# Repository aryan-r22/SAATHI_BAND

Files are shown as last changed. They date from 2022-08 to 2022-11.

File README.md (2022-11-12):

# SAATHI - Self Assessment & Alleviation by Technology & Healthcare Interface
## **Smart India Hackathon 2022 & Inter IIT Tech Meet 10.0**

### Description
SAATHI is an end-to-end IoT-based solution to help patients with anxiety spectrum disorders, track their mental health status, manage their cognitive behavior, and help them mitigate their issues by using a Smart wearable wristband and a mobile-based application which can be downloaded from [here](https://drive.google.com/file/d/1PYBU-KG3LGyAz-N6EyMyOQ441DeFL92f/view?usp=sharing).

### Directory Structure
- **End to end simulation files**: Consists of simulation files, circuit diagrams, codes and the necessary libraries for the MCU. Also included is a demonstration video for the entire implementation.
- **Fall detection**: Consists of scripts for implementing the algorithm for Fall detection.
- **Prototype 3DModel** - Consists of prototype files made on Fusion360.
- **Sleep detection** - Files for implementing the algorithm for Sleep detection.
- **Deployable codebase** - Single wrapper file for inference.
- **Stress_detection.ipynb** - Jupyter notebook to implement the stress detection algorithm.
- **SAATHI user flow.pdf**- A user flow diagram for the entire technical implementation of SAATHI.
- **Circuit Schematic Image.png** - The circuit schematic image for the entire approach.
- **Business Model Canvas.docx** - Document having the business model pictographics.
- **Anxiety Attack.pdf** - Flow diagram for anxiety attack detection algorithm.
- **Flow_OCD.pdf** - Flow diagram for OCD detection.
- **Important Links.xlsx** - Contains links for the references used for the entire project.
- **Finance Model.xlsx** - Contains data for the finance model of the entire product.
- **SAATHI.apk** - Mobile application for SAATHI ecosystem.
- **Final_Presentation** - Final pitch presentation.
- **Mid_Evaluation_Report** - Technical Report for the product.
- **SAATHI UI.mp4** - Mockup of the proposed UI for the mobile app.
- **Stress_Detection.ipynb** - Code file for stress detection.  

### Contributors
- Aditya Bharadwaj
- Aditya Naik
- Apurva Kamble
- Aryan Rastogi
- Ashish Gautam
- Ashwin Jino V
- Dhruv Parasrampuria
- Harshwardhan Chaube
- Kailaash Pandiyan
- Neelanshu Garg
- Samhith Damani
- V Logashree
- Vineet Tripathi

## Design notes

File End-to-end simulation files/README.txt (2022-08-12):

This folder has the following contents:

1) Libraries of the sensor modules used for proteus simulation - Proteus Libraries
2) Proteus project files in a folder.
3) A video explaining the end-to-end simulation - SAATHI end-to-end simulation.mp4
4) Arduino file used for simulation - Saathi.ino

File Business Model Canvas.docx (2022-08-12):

Business Model Canvas

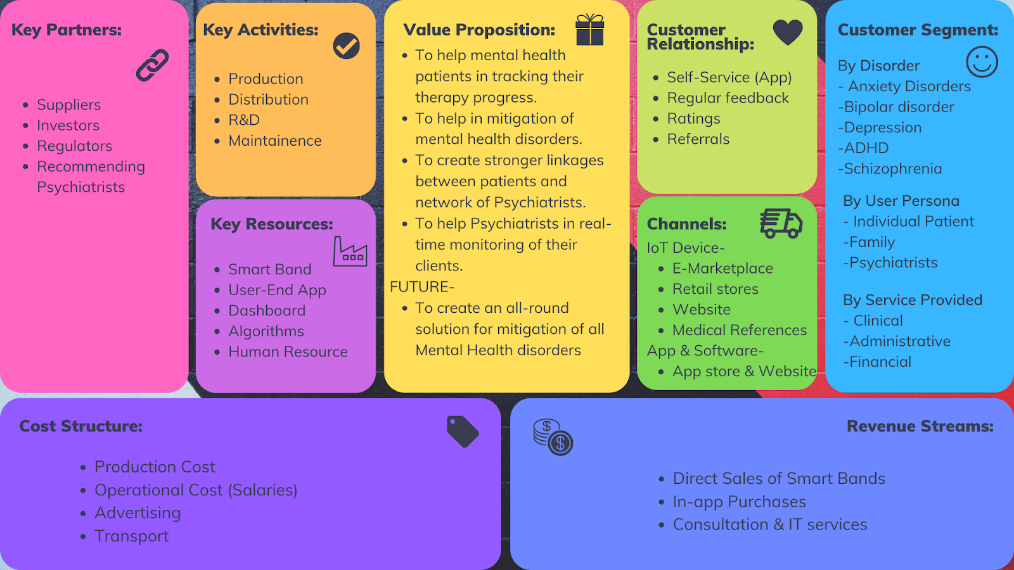
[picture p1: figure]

Unique Value proposition

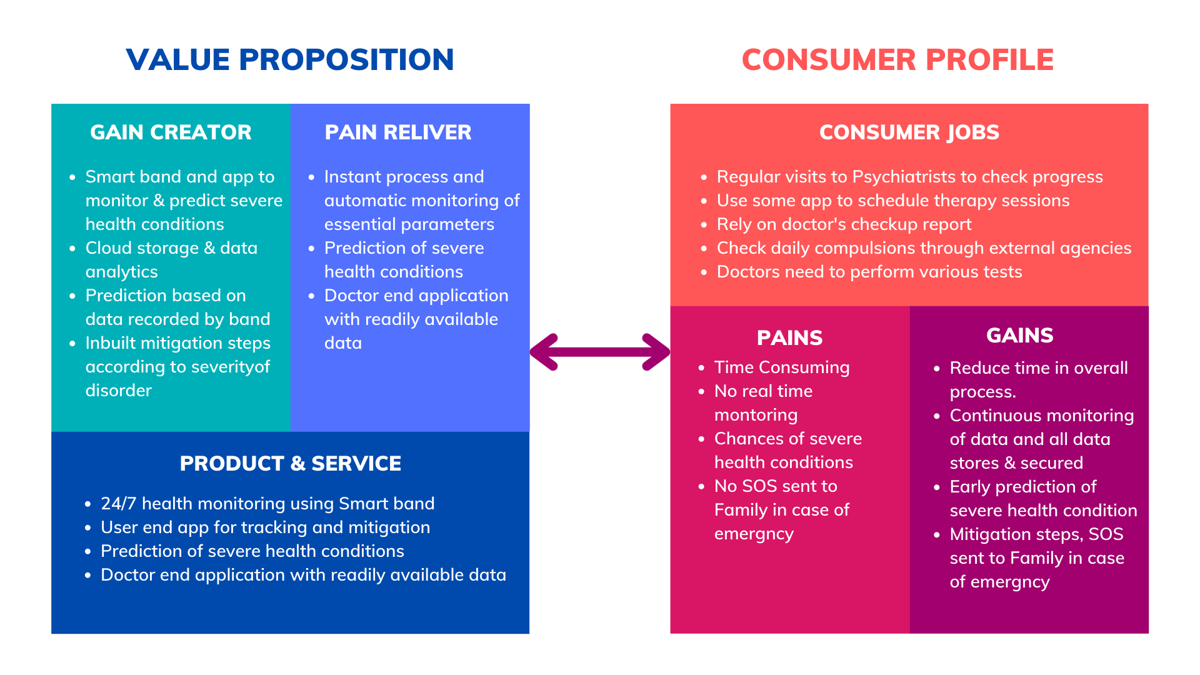
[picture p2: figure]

Customer Segmentation

As mental health is a very huge domain, we focus to help people with anxiety spectrum disorders. The product also lies in an affordable range and requires minimum internet connectivity, Hence it is meant for all sections of society

Persona 1 (Individual Patients)- Unable to track progress, Cannot store daily data. Do not have a personalized treatment plan.

Persona 2 (Family)- Keep track of the status of loved ones. Encourage family & community support.

Persona 3 (Psychiatrist)- Need for the patient management system. Need for data during consultation.

Customer Channels

Distribution channels include Physical & Virtual channels as follows-

Physical Channel This channel is only applicable for IoT devices (Smart Band). Physical sale in Pharmacy shops. Referrals by other patients and doctors | Virtual channel For IoT devices- InApp Purchases, Website, E-Marketplace For App- Appstore & Website For Software- Website

Customer Relationship

The healthy relationship between users and company can be marked by-

- Regular feedback of prediction model.
- Regular feedback of App support.
- Referrals of App/Bands.
- Ratings on several websites.

Revenue Stream

All these customer-side business interventions will generate revenue streams for the company.

Details- https://docs.google.com/spreadsheets/d/1tGmC5ilvg3ST7chS3FKTNZqF0qSboc8x575JbDMljg8/edit?usp=sharing

Key Activities

This includes a crucial part of the Business Value chain. The main operation of the Business is concerned with the Production, Distribution of smart devices, advertising, and maintenance.

Frequent updates in App and Software, Database management, Other business legalities.

Giving impetus to Research and Development for the launch of new products/services. Also taking its due approval from BIS or any other certifying agency.

Key Resources

Our key resources include all the essential files/codes/product from the origination to the termination of the value chain. Human Capital.

Key Partners

These include regulators those who approve our products, Psychiatrists who recommend our products, Investors as well as suppliers

Cost Structure

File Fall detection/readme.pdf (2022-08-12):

# Fall detection using Machine Learning -SAATHI

## Team 17 - Silicon Labs Entreprenuership Challenge

Inter IIT Tech Meet 10.0

Description

This machine learning algorithm detects fall detection using accelerometer and gyroscope sensors, both of which are present in our IoT based healthcare solution.

We have used the XGBoost algorithm for fall detection, which is renowned for its performance and efficiency gains. The dataset used is SisFall: A Fall and Movement Dataset [1], (http://sistemic.udea.edu.co/en/investigacion/proyectos/english-falls/) which is available in open domain. We envision our model to be dynamically trained on the data collected by our device, which ensures that our algorithm adapts to the the different variations in external conditions of use.

Running the code

Download the dataset zip files from the following links:

https://drive.google.com/uc?id=1gvOuxPc8dNgTnxuvPcVuCKifOf98-TV0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

Run Data_preparation.py to prepare the data in the required format for training.
Run Train.py to train the XGBoost model on the generated data and save the trained model for future inference.
Run Eval.py to get the metrics on the test split of the SisFall dataset.

Metrics on Test Split

Classification Accuracy = 98.04%
F1 Score (Weighted) = 97.95%
Precision (Weighted) = 97.92%
Recall (Weighted) = 98.04%

Our model performs exceptionally well, and exceeds the performance of the existing approaches on this dataset [2]. (https://www.ncbi.nlm.nih.gov/pmc/articles/PMC5298771/)

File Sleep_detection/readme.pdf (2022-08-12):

# Sleep detection using Machine Learning -SAATHI

## Team 17 - Silicon Labs Entreprenuership Challenge

Inter IIT Tech Meet 10.0

Description

This machine learning algorithm detects the sleep cycles on the basis of the accelerometer data recorded by our IoT-based healthcare solution.

We have used the XGBoost algorithm for fall detection, which is renowned for its performance and efficiency gains. Principal Component Analysis (PCA) was additionally used to transform the data to a lower dimension. The dataset used is ICHI 14 [1], (https://www.researchgate.net/publication/305212784_ICHI14-Borazio) which is available in open domain. We envision our model to be dynamically trained on the data collected by our device, which ensures that our algorithm adapts to the the different variations in external conditions of use.

Our machine learning algorithm provides predictions regarding the sleep stages under three heads, namely:

Mild Sleep (Label 0): corresponds to NoREM sleep stages 1-3.
Deep Sleep (Label 1): corresponds to REM sleep stage.
Awake (Label 2): corresponds to awake/movement.

We removed the data points which were labelled as unknown as they did not contribute to the model training and evaluation in any way whatsoever.

Running the code

Install the following packages

numpy==1.16.1
pandas==0.25.1

Download the dataset zip files from the following link:

https://www.researchgate.net/publication/305212784_ICHI14-Borazio

Unzip the dataset and place the individual .npy files in the data subfolder as ./ICHI14 dataset/*
Ensure to remove the irrelevant file pat_inf.npy file from the above directory.
Run Data_preparation.py to prepare the data in the required format for training.
Run Train.py to train the XGBoost model on the generated data and save the trained model for future inference.
Run Eval.py to get the metrics on the test split of the ICHI 14 dataset.

Metrics on Test Split

Classification Accuracy = 74.12%
F1 Score (Weighted) = 73.43%

Precision (Weighted) = 72.88%
Recall (Weighted) = 74.12%

We found that our metrics are consistent and are at par with the existing research studies on the same dataset [2]. (https://par.nsf.gov/servlets/purl/10073179) The pretrained model may be trained dynamically on the recorded data from the use of our device, which may further increase its predictive capabilities over the long term.

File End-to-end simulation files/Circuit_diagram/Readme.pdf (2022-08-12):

TEAM-17 - SAATHI
Saathi_Prototype\Readme:

You are currently viewing Saathi_Prototype\Readme.pdf

- Saathi_Prototype\Circuit.fzz
Circuit.fzz can be opened using fritzing (https://fritzing.org/) where a breadboard view, a Schematic and a PCB view can be seen.
- Saathi_Prototype\Circuit.png
- Saathi_Prototype\PCB.png
- Saathi_Prototype\Schematic.png
- Saathi_Prototype\Firmware
This directory contains all the required libraries for the Arduino Nano to interface with the sensors and other modules used in the prototype.
- Saathi_Prototype\Firmware\Firmware.ino
Firmware.ino is an interactive test code written on the Arduino IDE. (https://www.arduino.cc/en/software) You can simply open the Firmware.ino file using the Arduino IDE and it will automatically initialize the libraries present in the same directory.

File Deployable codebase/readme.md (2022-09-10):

# Deployable code
## Team 17 - Silicon Labs Entreprenuership Challenge
### **Inter IIT Tech Meet 10.0**

### Description
This codebase implements stress, fall and sleep detection wrapped in a single script. Uses `../Fall detection` and `../Sleep_detection` for generating trained model files.  

### Running the code

- Install required dependencies
- Ensure that the input datafile is in the same format as `all.csv`.  
- Run `runner.py` to generate prediction files.   

### References
- S. Uday, C. Jyotsna and J. Amudha, "Detection of Stress using Wearable Sensors in IoT Platform," 2018 Second International Conference on Inventive Communication and Computational Technologies (ICICCT), 2018, pp. 492-498, doi: 10.1109/ICICCT.2018.8473010.  
- Jonathan Rubin, Hoda Eldardiry, Rui Abreu, Shane Ahern, Honglu Du, Ashish Pattekar, and Daniel G. Bobrow. 2015. Towards a mobile and wearable system for predicting panic attacks. In Proceedings of the 2015 ACM International Joint Conference on Pervasive and Ubiquitous Computing (UbiComp '15). Association for Computing Machinery, New York, NY, USA, 529–533, doi: 10.1145/2750858.2805834.

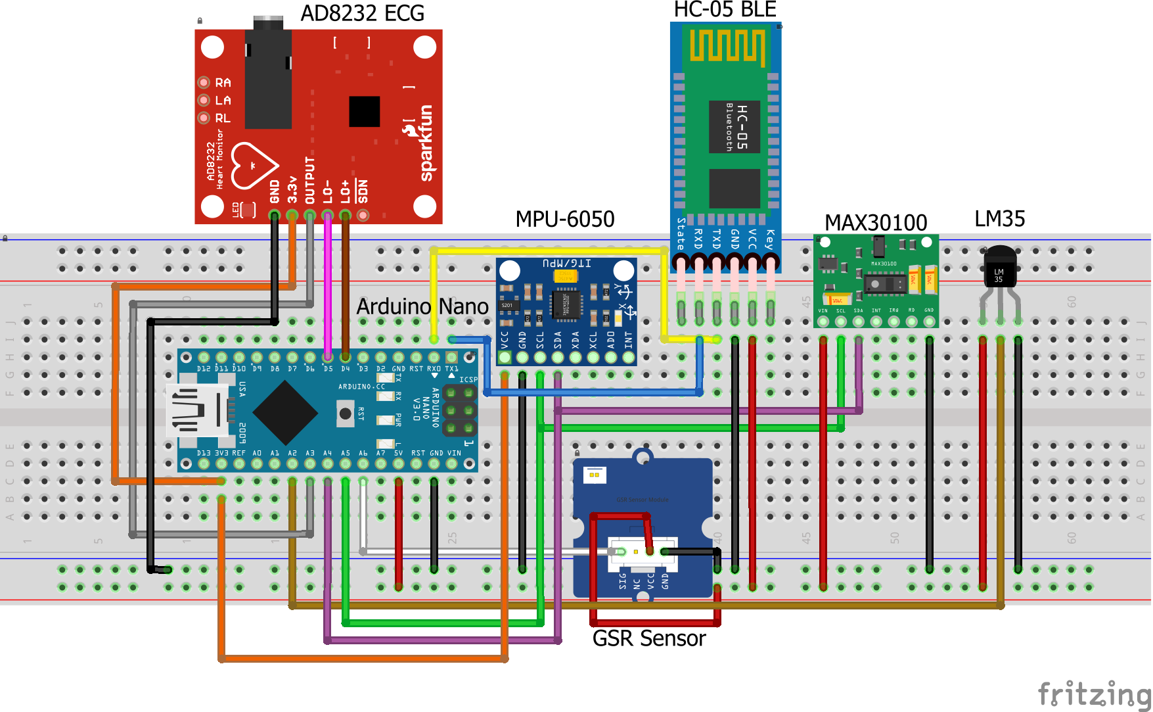
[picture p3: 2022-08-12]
Circuit Schematic.png

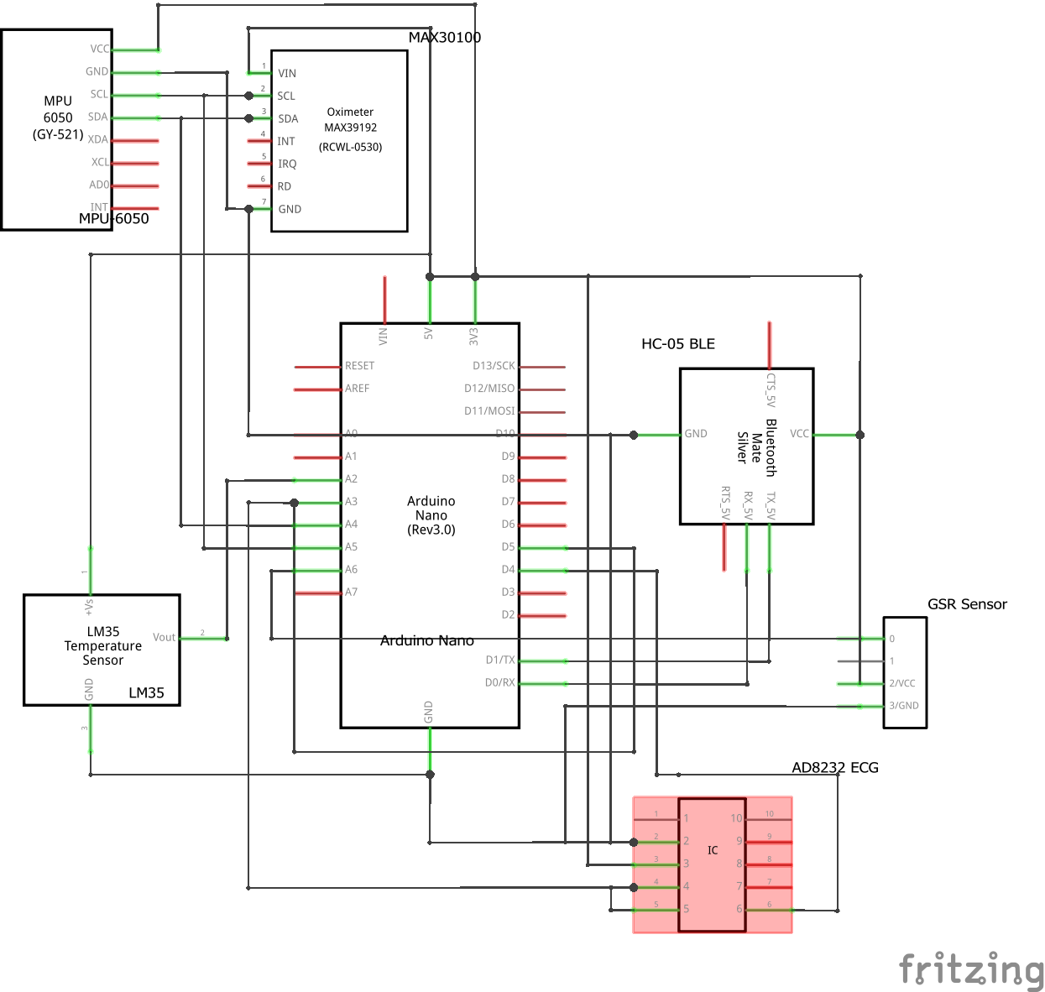
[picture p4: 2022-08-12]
End-to-end simulation files/Circuit_diagram/Schematic.png

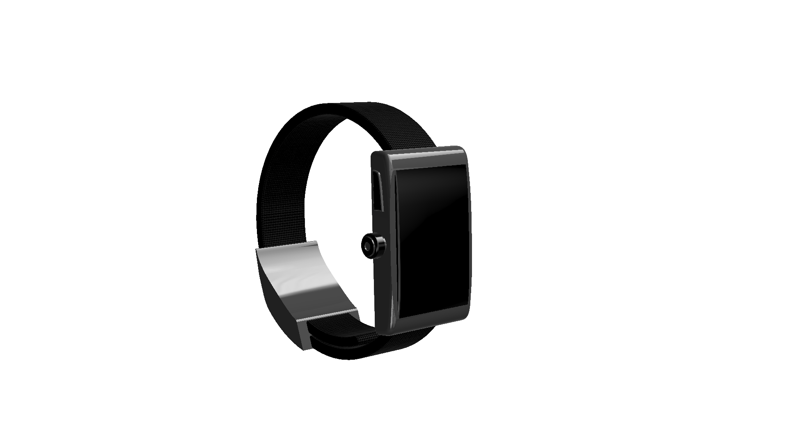
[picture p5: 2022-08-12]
Prototype_3DModel/wb1.png

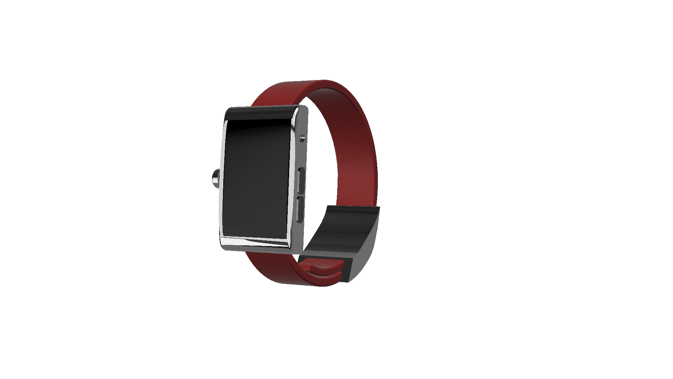
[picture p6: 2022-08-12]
Prototype_3DModel/w4.png

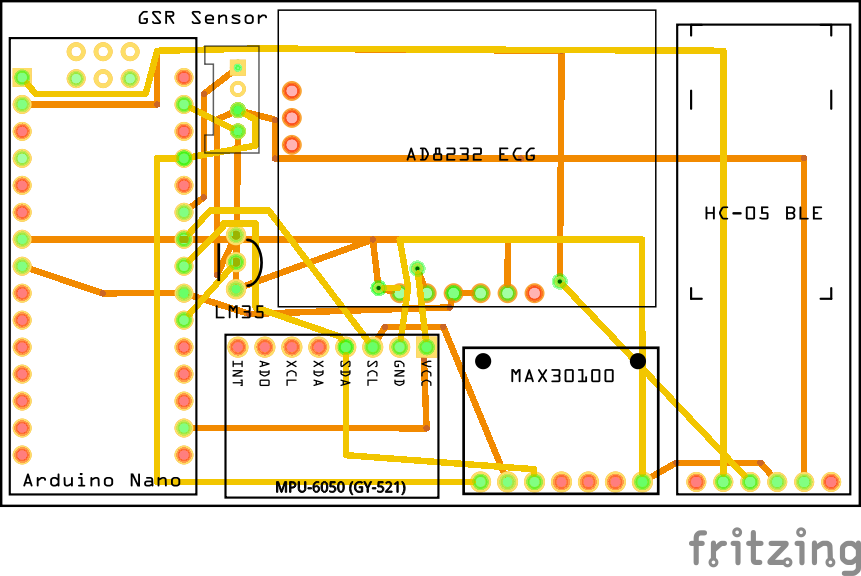
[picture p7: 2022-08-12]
End-to-end simulation files/Circuit_diagram/PCB.png

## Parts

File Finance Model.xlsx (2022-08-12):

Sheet: Expenditure
PRODUCTION COST |  | OPERATIONAL COST
Sensor Required for The device | retail costing | Operators | no. | Expenditure per person | Total Expenditure
Arduino nano | ₹499 | Average Salary of employees | ₹100 | ₹500000 | ₹50000000
EDA - Skin Conductance (SeeedStudio Grove GSR sensor) | ₹820 | Rent | - | - | ₹2000000
LM35 Temprature sensor | ₹53 | TOTAL fixed cost |  |  | ₹52000000
ECG Sensor Module (AD8232) | ₹650
MPU6050 Gyro-Accelerometer | ₹1000
Pulse Oximeter Heart Rate Sensor Module (MAX30100) | ₹160 | Transportation cost | - | - | ₹5000000
 |  | Advertising | - | - | ₹5000000
Total | ₹3182 | Business essentials (legal service,etc.) | - | - | ₹1000000
 |  | TOTAL variable cost |  |  | ₹11000000
Bulk production cost of the components | 70% of Retail cost
 |  | Annual operating costs | ₹63000000
Additional cost to production | Percentage in bulk prod cost
Packaging | 2% | MARKET CAP GUESSTIMATES
Governmental Taxation | 18% | Parameter | Assumed percentage | Value
Actual production cost Per Unit | 2673 INR | Population of India | - | 1,30,00,00,000
 |  | No. of people suffering from Anxiety Sprectum Disorder | 2% | 2,60,00,000
Production Cost | 2673*65000 =INR 17,37,45,000 | No. of people that can afford tele-health services | 5% | 13,00,000
 |  | Market capitalization of our brand/product (Potential customers) | 5% | 65000

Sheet: Revenue
REVENUE
Revenue Stream | Price per product | estimated yearly sales | Revenue Generated
Operating Revenue (through direct sales) | ₹4000 | 65000 | 260000000
In-App purchases (premium service) | ₹500 | 30000 | 1500000
Software solutions to Doctor/Hospitals | Free | 0 | 0
TOTAL REVENUE Generated |  |  | 261500000

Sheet: P&L and Growth
Yearly Inflation in production= 5% | Source: Statista
Customer Growth rate= 8%
Fixed cost growth= 1%
 | Financial Year 1 | Financial Year 2 | Financial Year 3 | Financial Year 4 | Financial Year 5 | FY 1
Projected revenue | 261500000 | 282420000 | 305013600 | 329414688 | 355767863 | Price to earning ratio= 236745000/24755000= 9.56 INR
Projected Production costs | 173745000 | 182432250 | 191553863 | 201131556 | 211188133
Fixed Costs | 63000000 | 63630000 | 64266300 | 64908963 | 65558053
Profits | 24755000 | 36357750 | 49193437 | 63374169 | 79021677
 |  |  |  |  |  | FY 5
 |  |  |  |  |  | Price to earning ratio= 276746186/79021677= 3.5 INR

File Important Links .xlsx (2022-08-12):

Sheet: Tech Research
ARTICLE | LINK
General Content
Smart Wearable Device for Health Monitoring in the Internet of Things (IoT) Domain | https://dl.acm.org/doi/pdf/10.5555/3015574.3015610
Future Fitbit wearable could offer mental state monitoring and mood tracking at a potential privacy cost | https://www.notebookcheck.net/Future-Fitbit-wearable-could-offer-mental-state-monitoring-and-mood-tracking-at-a-potential-privacy-cost.588440.0.html
Fitbit: Determining mental health and cognitive state through physiological and other non-invasively obtained data | https://patents.justia.com/patent/11191466
How Accurate are ECG Parameters from Wearable Single-lead ECG System for 24-hours Monitoring | https://sci-hub.hkvisa.net/https://ieeexplore.ieee.org/document/9005946
5 Indian startups working on mental health | https://startuptalky.com/top-mental-health-startups-india/
 | https://create.arduino.cc/projecthub/factoryeight/emotion-towards-a-better-future-a01489
Stress Detection
An intelligent stress detection and monitoring system using the IoT environment : Youtube Sam Hadhri | https://www.youtube.com/watch?v=VmyrZ_C2rj8&ab_channel=SamiHadhri
Stress Detection using Wearable Physiological Sensors | https://eprints.lancs.ac.uk/id/eprint/76167/1/proof.pdf
Continuous Stress Detection Using Wearable Sensors in Real Life: Algorithmic Programming Contest Case Study | https://www.ncbi.nlm.nih.gov/pmc/articles/PMC6515276/
WESAD Dataset | https://archive.ics.uci.edu/ml/datasets/WESAD+%28Wearable+Stress+and+Affect+Detection%29
Anxiety Attack
Towards a Mobile and Wearable System for Predicting Panic Attacks | https://www.researchgate.net/publication/308056859_Towards_a_mobile_and_wearable_system_for_predicting_panic_attacks
UT Dallas: Wearable Device for the Management of Panic Attacks | https://cpb-us-e2.wpmucdn.com/sites.utdallas.edu/dist/2/981/files/699-Wearable-Device-for-the-Management-of-Panic-Attacks.pdf
UT Dallas: Wearable Device for the Management of Panic Attacks | https://cpb-us-e2.wpmucdn.com/sites.utdallas.edu/dist/0/381/files/Team-699-Wearable-Device-For-Panic-Attack-Management.pdf
Panic Attack Prediction Using Wearable Devices and Machine Learning: Development and Cohort Study | https://medinform.jmir.org/2022/2/e33063/
OCD
Recognition of Hand Gesture Sequences by Accelerometers and Gyroscopes | https://www.researchgate.net/publication/345207777_Recognition_of_Hand_Gesture_Sequences_by_Accelerometers_and_Gyroscopes
Smartphone-Based Recognition of Human Activities and Postural Transitions Data Set : UCI | http://archive.ics.uci.edu/ml/datasets/Smartphone-Based+Recognition+of+Human+Activities+and+Postural+Transitions
IoT+Small Data: Transforming In-Store ShoppingAnalytics & Services : Page-3, bottom left para for compulsion detection | https://www.researchgate.net/publication/301286816_IoTSmall_Data_Transforming_In-Store_Shopping_Analytics_Services
Action detection using ESP32 and MPU6050: TinyML: Machine Learning on ESP32 with MicroPython | https://dev.to/tkeyo/tinyml-machine-learning-on-esp32-with-micropython-38a6
Seep Quality
Hindawi: IoT Healthcare: Design of Smart and Cost-Effective Sleep Quality Monitoring System | https://www.hindawi.com/journals/js/2020/8882378/
SleePy | https://joss.theoj.org/papers/10.21105/joss.01663.pdf | https://github.com/elyiorgos/sleeppy
pyActigraphy | https://github.com/ghammad/pyActigraphy
Sleep classification from wrist-worn accelerometer data using random forests | https://www.nature.com/articles/s41598-020-79217-x
Estimating sleep parameters using an accelerometer without sleep diary | https://www.ncbi.nlm.nih.gov/pmc/articles/PMC6113241/
Dataset: Motion and heart rate from a wrist-worn wearable and labeled sleep from polysomnography | https://physionet.org/content/sleep-accel/1.0.0/ | https://github.com/ojwalch/sleep_classifiers/
Dataset: One Year of Actigraphy | https://sleepdata.org/datasets/oya
An Active Sleep Monitoring Framework Using Wearables | https://par.nsf.gov/servlets/purl/10073179
Fall Detection
Development of a Wearable-Sensor-Based Fall Detection System | https://www.hindawi.com/journals/ijta/2015/576364/
Improving Fall Detection Using an On-Wrist Wearable Accelerometer | https://www.researchgate.net/publication/324799239_Improving_Fall_Detection_Using_an_On-Wrist_Wearable_Accelerometer/link/5ae31be5aca272fdaf8fddbc/download
Threshold-based Fall Detection on Smart Phones | https://www.researchgate.net/publication/262751956_Threshold-based_Fall_Detection_on_Smart_Phones
Mobiact dataset : Fall detection | https://www.researchgate.net/publication/302973506_The_MobiAct_Dataset_Recognition_of_Activities_of_Daily_Living_using_Smartphones/link/59c73ef1aca272c71bc3f3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
Fall detection - Sisfall dataset | https://github.com/suyash16999/Fall-Detection-System
Sisfall Fall detection | https://www.ncbi.nlm.nih.gov/pmc/articles/PMC5298771/

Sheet: Market Research
ARTICLE | LINK
World data & in depth articles | https://ourworldindata.org/mental-health
Global Market Report | https://www.google.com/amp/s/www.alliedmarketresearch.com/mental-health-market/amp
Indian Market report | https://healtharkinsights.com/wp-content/uploads/2021/10/Digital-Mental-Health-Innovations-in-India.pdf
Indian Startups | https://yourstory.com/socialstory/2021/10/startups-mental-health-wysa-epsyclinic/amp
Startups issues | https://economictimes.indiatimes.com/tech/startups/why-have-mental-health-startups-not-taken-off-in-india/articleshow/85835762.cms
Drug sales | https://economictimes.indiatimes.com/industry/healthcare/biotech/healthcare/drug-sales-show-the-times-are-bad-for-mental-health/articleshow/84422395.cms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
Venture funding US | https://www.forbes.com/sites/katiejennings/2021/06/07/venture-funding-for-mental-health-startups-hits-record-high-as-anxiety-depression-skyrocket/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

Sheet: PM
ARTICLE | LINK
Product Vision | https://startinfinity.com/product-management-framework/product-strategy/defining-product-vision
Product Strategy | https://www.productplan.com/learn/guide-to-product-strategy/
Market Research | https://medium.com/agileinsider/the-ultimate-guide-to-b2b-customer-research-d0ee599ea986
MVP | https://lanars.com/blog/what-does-mvp-mean-and-why-you-need-it
Agile Methodology | https://www.youtube.com/watch?v=WjwEh15M5Rw
Value proposition | https://www.youtube.com/watch?v=kiWkRiynPAo
Business Model Canvas | https://www.youtube.com/watch?v=IP0cUBWTgpY
Business Model Canvas | https://www.strategyzer.com/business-model-canvas/value-propositions

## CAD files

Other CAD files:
Prototype_3DModel/watch v3.f3d

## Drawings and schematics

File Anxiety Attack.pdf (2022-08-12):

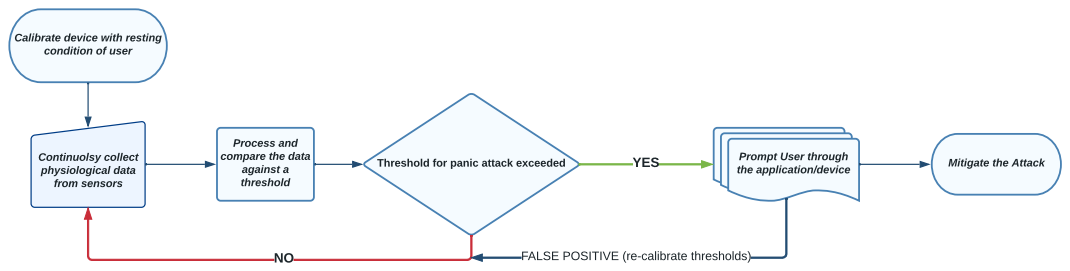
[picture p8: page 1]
Continuolsy collect physiological data from sensors; Threshold for panic attack exceeded; Prompt User through; YES; FALSE POSITIVE (re-calibrate thresholds)

Calibrate device with resting
condition of user

Process and
compare the data
against a
threshold

the application/device

Mitigate the Attack

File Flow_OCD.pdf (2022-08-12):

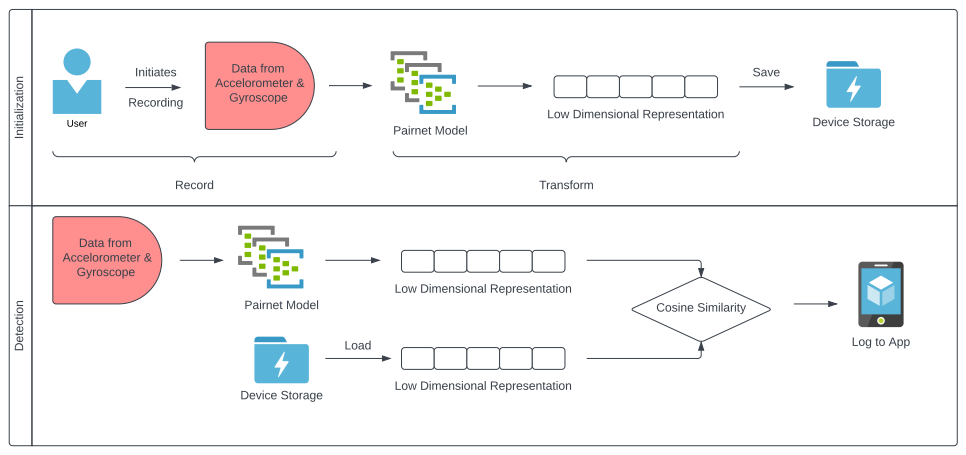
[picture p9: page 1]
Pairnet Model; Data from Accelorometer & Gyroscope; Save; User; Initiates; Recording; Device Storage; Record; Transform; Cosine Similarity; Load

Low Dimensional Representation

Log to App

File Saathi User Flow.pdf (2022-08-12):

## SAATHI's SERVER

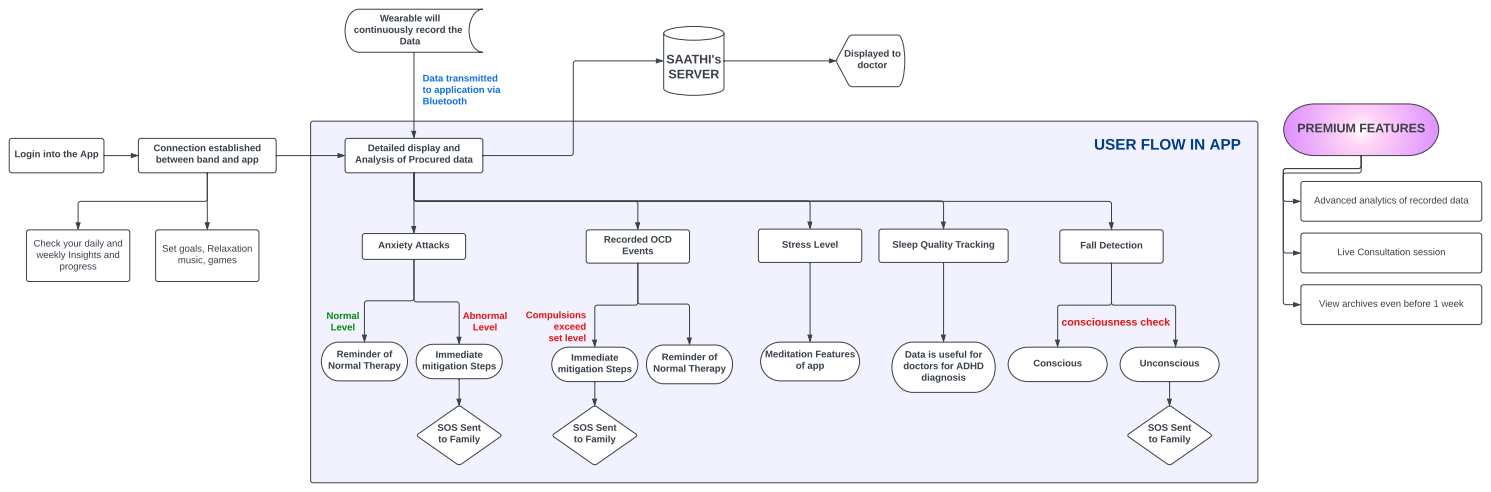
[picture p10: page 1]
Normal Level; consciousness check; Data; Anxiety Attacks; Recorded OCD Events; Stress Level; Sleep Quality Tracking; Fall Detection; Reminder of Normal Therapy; Immediate mitigation Steps; Abnormal Level; Displayed to doctor; Compulsions exceed set level; Meditation Features of app; Conscious; Unconscious; SOS Sent to Family; PREMIUM FEATURES

Wearable will
continuously record the

Data transmitted
to application via
Bluetooth

USER FLOW IN APP

Login into the App

Connection established
between band and app

Detailed display and
Analysis of Procured data

Advanced analytics of recorded data

Check your daily and
weekly Insights and
progress

Set goals, Relaxation
music, games

Live Consultation session

View archives even before 1 week

Data is useful for
doctors for ADHD
diagnosis

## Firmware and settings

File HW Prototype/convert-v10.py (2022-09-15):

#import pandas as pd
#import firebase_admin
import serial
import time
from datetime import datetime

from smbus2 import SMBus        #For MLX90614
from mlx90614 import MLX90614

from flask import Flask
app=Flask(__name__)

@app.route("/")

def data():
    return global_variable_data

##firebase credentials
#from firebase_admin import credentials, firestore
#cred = credentials.Certificate('./saathi-c9678-firebase-adminsdk-qj7we-6c75ef6a2e.json');
#firebase_admin.initialize_app(cred, 
#{
#'databaseURL': 'https://saathi-c9678.firebaseio.com/'
#})
#db = firestore.client()
## doc_ref = db.collection(u’applications’)
#doc_ref=db.collection('users').document('uid7').collection('sensorReadings')

#Serial port setup , change baud and serial port
ser = serial.Serial('/dev/ttyUSB0', 115200)
ser.baudrate = 115200
#ser.port = 'COM5' #Already selected
#ser.open()        #Already open

#to buffer the incoming data
class ReadLine:
    def __init__(self, s):
        self.buf = bytearray()
        self.s = s
    
    def readline(self):
        i = self.buf.find(b"\n")
        if i >= 0:
            r = self.buf[:i+1]
            self.buf = self.buf[i+1:]
            return r
        while True:
            i = max(1, min(2048, self.s.in_waiting))
            data = self.s.read(i)
            i = data.find(b"\n")
            if i >= 0:
                r = self.buf + data[:i+1]
                self.buf[0:] = data[i+1:]
                return r
            else:
                self.buf.extend(data)

rl = ReadLine(ser)

samples=100 #number of data to be sent to cloud in one cycle
counter100 = 0

#garbage file data number defination
garbage_data=10
garbageline=0
garbage_data2=15
garbageline2=0
#definging and processing headers
headers="GFORCEX,GFORCEY,GFORCEZ,ROT_X,ROT_Y,ROT_Z,GSR,HEARTRATE,SpO2 %,AMB TEMP MLX, OBJ TEMP MLX"  #Added TEMP MLX for the MLX90614
headers=headers.rstrip()

#garbaging the initial sensor values
file = open("garbage.csv", "w" )
print("Created file")

while(garbageline < garbage_data):
    getData=str(rl.readline())
    data_garbage=getData
    #print(data_garbage)        
    garbageline=garbageline+1

print("first garbage disposal complete")
file.close()

#infinite loop to send data from serial to cloud
while(1):
    file = open("garbage2.csv", "w" )
    print("Created file")

    if __name__ =="__main__":
        app.run(host="0.0.0.0", port=80, debug=True)

    while(garbageline2 < garbage_data2):
        getData=str(rl.readline())
        data_garbage2=getData
     #print(data_garbage2)        
        garbageline2=garbageline2+1

    print("SECOND Garbage disposal complete")
    file.close()

    file = open("all.csv", "w" )
    print("Created file")

    line=0

    print("writing data to file " + "all.csv")
    while( line <= samples ):
        bus = SMBus(1)
        tempSensor = MLX90614(bus, address=0x5A)
        if line==0:
            print("Printing Column Headers")
            print(headers)
            file.write(headers + "\n")
        else:
            print("Line " + str(line) + ": writing...")
        
        mlx_amb_temp = tempSensor.get_amb_temp()
        mlx_obj_temp = tempSensor.get_obj_temp()
        getData=(str(rl.readline().decode('utf-8').rstrip()) + "," + str(round(mlx_amb_temp,2)) + "," + str(round(mlx_obj_temp,2)))
        data=getData
        global_variable_data=data
        print (datetime.now())
        print(data)

        file=open("all.csv", "a")
        file.write(data + "\n")
        bus.close()
        
        line=line+1

    print("writing complete")
    file.close()
    counter100 = counter100 + 1
    print("Counter100: " + str(counter100))
    print("Uploading data to the cloud...")

    

    #df = pd.read_csv('all.csv')
    #tmp = df.to_dict(orient='records')
    #list(map(lambda x: doc_ref.add(x), tmp))
    ser.reset_input_buffer()
    time.sleep(0.2)

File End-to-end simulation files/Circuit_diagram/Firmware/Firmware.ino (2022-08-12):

// Including Libraries
#include "Arduino.h"
#include "BTHC05.h"
#include "LM35.h"
#include "MPU6050.h"
#include "Wire.h"
#include "I2Cdev.h"
#include "MAX30100.h"

// Pin Definitions
#define BTHC05_PIN_TXD  1
#define BTHC05_PIN_RXD  0
#define LOplus  4            // Setup for leads off detection LO +
#define LOminus  5           // Setup for leads off detection LO -
#define HEARTRATE_PIN_SIG A3
#define LM35_PIN_VOUT  A2
#define GSR_PIN_SIG  A6

// Global variables and defines
int16_t mpu6050Ax, mpu6050Ay, mpu6050Az;
int16_t mpu6050Gx, mpu6050Gy, mpu6050Gz;
int gsr_val = 0;
int gsr_avg = 0;

// object initialization
BTHC05 bthc05(BTHC05_PIN_RXD,BTHC05_PIN_TXD);
LM35 lm35(LM35_PIN_VOUT);
MPU6050 mpu6050;

// defining vars for testing menu
const int timeout = 10000;       //defining timeout of 10 sec
char menuOption = 0;
long time0;

void setup()
{
  // Setup Serial which is useful for debugging
  // Use the Serial Monitor to view printed messages
  Serial.begin(9600);
  while (!Serial) ; // wait for serial port to connect. Needed for native USB
  Serial.println("start");
  
  bthc05.begin(9600);
  //This example uses HC-05 Bluetooth to communicate with an Android device.
  //Download bluetooth terminal from google play store, https://play.google.com/store/apps/details?id=Qwerty.BluetoothTerminal&hl=en
  //Pair and connect to 'HC-05', the default password for connection is '1234'.
  //You should see this message from your arduino on your android device
  bthc05.println("Bluetooth On....");
  Wire.begin();
  mpu6050.initialize();
  menuOption = menu();
}

void loop() 
{
  if(menuOption == '1') 
  {
    // LM35DZ - Temperature Sensor - Test Code
    //Get Measurment from LM35 temperature sensor.
    float lm35TempC = lm35.getTempC();
    Serial.print(F("Temp: ")); Serial.print(lm35TempC); Serial.println(F("[°C]"));
  }
  else if(menuOption == '2') 
  {
    // HC-05 Bluetooth Module Test Code
    String bthc05Str = "";
    //Receive String from bluetooth device
    if (bthc05.available()) 
    {
      //Read a line from bluetooth terminal
      bthc05Str = bthc05.readStringUntil('\n');
      // Printing data to serial monitor
      Serial.print("BT Raw Data: ");
      Serial.println(bthc05Str);
    }
    //Send sensor data to Bluetooth device
    bthc05.println("Sensor data can be put here");
  }
  else if(menuOption == '3')
  {
    // AD8232 ECG Sensor Test code
    if((digitalRead(LOplus) == 1)||(digitalRead(LOminus) == 1))
    {
      Serial.println('!');
    }
    else
    {
      // send the value of analog input 0:
      Serial.println(analogRead(A3));
    }
    delay(1);          //Wait for a bit to prevent serial data from saturating
  }
  else if(menuOption == '4')
  {
    // MAX30100 - Heart Rate and SpO2 Test code To be added
  }
  else if(menuOption == '5') 
  {
    // MPU-6050 - Accelerometer and Gyro - Test Code
    mpu6050.getMotion6(&mpu6050Ax, &mpu6050Ay, &mpu6050Az, &mpu6050Gx, &mpu6050Gy, &mpu6050Gz);   //read accelerometer and gyroscope raw data in three axes
    double mpu6050Temp = ((double)mpu6050.getTemperature() + 12412.0) / 340.0;
    Serial.print("a/g-\t");
    Serial.print(mpu6050Ax); Serial.print("\t");
    Serial.print(mpu6050Ay); Serial.print("\t");
    Serial.print(mpu6050Az); Serial.print("\t");
    Serial.print(mpu6050Gx); Serial.print("\t");
    Serial.print(mpu6050Gy); Serial.print("\t");
    Serial.print(mpu6050Gz); Serial.print("\t");
    Serial.print(F("Temp- "));   
    Serial.println(mpu6050Temp);
    delay(100);
  }
  else if(menuOption == '6') 
  {
    // GSR Sensor Module - Test Code
    long gsr_sum=0;
    for(int i=0;i<10;i++)              //Average the 10 measurements to remove the glitch
    {
      gsr_val=analogRead(GSR_PIN_SIG);
      gsr_sum += gsr_val;
      delay(5);
    }
    gsr_avg = gsr_sum/10;
    Serial.println(gsr_avg);
  }
  
  if (millis() - time0 > timeout)
  {
      menuOption = menu();
  }
}

// Menu function for selecting the components to be tested
char menu()
{
  Serial.println(F("\nWhich component would you like to test?"));
  Serial.println(F("(1) LM35DZ - Temperature Sensor"));
  Serial.println(F("(2) HC-05 Bluetooth Serial Module"));
  Serial.println(F("(3) AD8232 Analog Heart Rate Monitor Sensor (ECG"));
  Serial.println(F("(4) MAX30100 - Particle Sensor (HR & SpO2)"));
  Serial.println(F("(5) MPU-6050 - Accelerometer and Gyro"));
  Serial.println(F("(6) GSR Sensor Module"));
  Serial.println(F("(menu) send anything else or press on board reset button\n"));
  while (!Serial.available());
  
  // Read data from serial monitor if received
  while (Serial.available()) 
  {
    char c = Serial.read();
    if (isAlphaNumeric(c)) 
    {
      if(c == '1') 
        Serial.println(F("Now Testing LM35DZ - Temperature Sensor"));
      else if(c == '2')
        Serial.println(F("Now Testing HC-05 Bluetooth Serial Module"));
      else if(c == '3') 
        Serial.println(F("Now Testing AD8232 Analog Heart Rate Monitor Sensor (ECG)"));
      else if(c == '4') 
        Serial.println(F("MAX30100 - Now Testing Particle Sensor - No test code"));
      else if(c == '5') 
        Serial.println(F("Now Testing MPU-6050 - Accelerometer and Gyro"));
      else if(c == '6')
        Serial.println(F("Now Testing GSR Sensor Module"));
      else
      {
        Serial.println(F("Unexpected input!"));
        return 0;
      }
      time0 = millis();
      return c;
    }
  }
}

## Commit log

2022-09-10 Adding deployable ML models
    [Preds_Net_1661680221.csv, all.csv]
2022-09-15 Latest Versions
    Every latest version
    [all.csv, ashwin.csv, serverconverter.csv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]
2022-11-12 Adding the link to the android application
    The final version of the app on which we were able to see the live data from the sensors and algorithms along with Ayurveda-based recommendations.
